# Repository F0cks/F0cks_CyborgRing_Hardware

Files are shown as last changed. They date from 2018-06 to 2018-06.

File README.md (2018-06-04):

# F0cks_CyborgRing_Hardware

I have created my own hardware and software of **Zach Fredin** [zakqwy](https://github.com/zakqwy) Cyborg ring. You can use [my Cyborg ring software](https://github.com/F0cks/F0cks_CyborgRing_Hardware) for this hardware. <br />
You can find more information on my blog : [blog.f0cks.net/projects/Cyborg-ring](https://blog.f0cks.net/projects/Cyborg-ring/).

### Description

* This hardware has been created with **Eagle Version 7.7.0**.
* All GERBER files are included in **F0cks_CyborgRing_Gerber.zip**.
* You can create directly your board using my **OSHPark Project**: <br /> 
* I have added the **BOM** with component links from Digikey (and button cells from eBay).
* You will probably need to edit the board to fit the ring to your finger ( diameter is around 17mm).

## Authors

* **Geoffrey Enjolras** - [F0cks](https://github.com/F0cks)

## License

In agreement with **Zach Fredin**, this code is released under the terms of the Creative Commons Attribution-ShareAlike 4.0 license, available here: http://creativecommons.org/licenses/by-sa/4.0/.


## Acknowledgments

Completely inspired by **Zach Fredin** [zakqwy](https://github.com/zakqwy).

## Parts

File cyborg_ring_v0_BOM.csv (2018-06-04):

Qty | Value | Device | Package | Parts | Links
1 |  | PUSHBUTTON | BTN_CK_KSS | SW1 | https://www.digikey.fr/product-detail/fr/omron-electronics-inc-emc-div/B3U-3000P/SW1022CT-ND/1534359
1 | 100n | C-EUC0201 | C0201 | C1 | https://www.digikey.fr/product-detail/fr/samsung-electro-mechanics/CL03A104KP3NNNC/1276-1115-1-ND/3889201
1 | ATTINYX5V-LEFT | ATTINYX5V-LEFT | 1/4-QFN20 | U1 | https://www.digikey.fr/product-detail/fr/microchip-technology/ATTINY85V-15MT/1611-ATTINY85V-15MTCT-ND/6833275
0 | ATTINYX5V-RIGHT | ATTINYX5V-RIGHT | 1/4-QFN20 | U2 | /
2 | BAT+ | BAT+ | BAT+ | U$1, U$2 | https://www.ebay.fr/itm/Lot-de-piles-boutons-auditives-Rayovac-appareils-auditifs-A10-de-1-%C3%A0-60-piles/272609224796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
2 | BAT- | BAT- | BAT- | U$3, U$4 | https://www.digikey.fr/product-detail/fr/te-connectivity-amp-connectors/1447360-8/A108284CT-ND/4022011
16 | R0508-1/2 | R0508-1/2 | R0508-1/2 | R13, R14, R15, R16, R17, R18, R19, R20, R21, R22, R23, R24, R25, R26, R27, R28 | https://www.digikey.fr/product-detail/fr/rohm-semiconductor/LTR10EZPF22R0/RHM1211CT-ND/4055428
12 | R0805-1/2 | R0805-1/2 | R0805-1/2 | R1, R2, R3, R4, R5, R6, R7, R8, R9, R10, R11, R12 | https://www.digikey.fr/product-detail/fr/yageo/RC0805JR-070RL/311-0.0ARCT-ND/731163
1 | TPTP06R | TPTP06R | TP06R | PAD | /
6 | TPTP15R | TPTP15R | TP15R | GND, MISO, MOSI, RST, SCK, VCC | https://www.digikey.fr/product-detail/fr/mill-max-manufacturing-corp/821-22-006-10-000101/ED8197-06-ND/1146513
8 |  | LEDS |  |  | https://www.digikey.fr/product-detail/fr/kingbright/APT1608LSECK-J3-PRV/754-1930-1-ND/5177460

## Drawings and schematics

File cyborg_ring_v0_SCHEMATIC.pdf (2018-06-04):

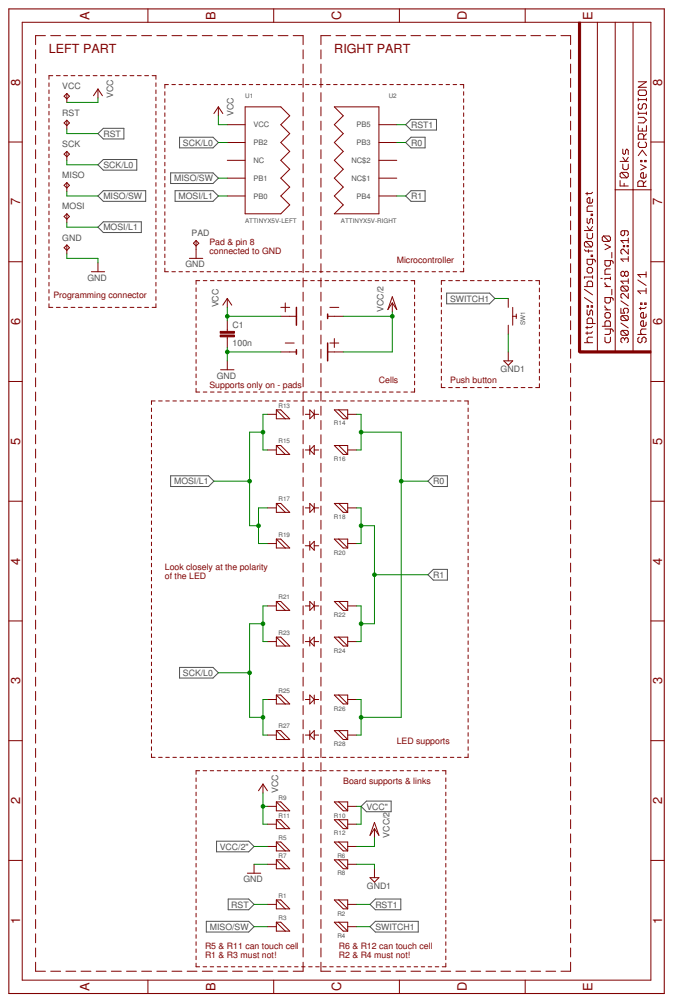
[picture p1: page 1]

GND
Supports only on - pads

Look closely at the polarity of the LED

LED supports Board supports & links

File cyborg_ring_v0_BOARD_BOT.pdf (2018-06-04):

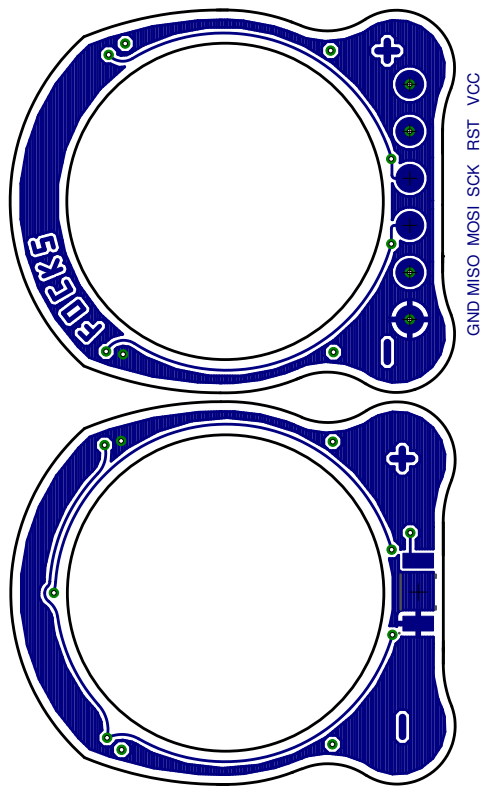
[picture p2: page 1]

GND MISO MOSI SCK RST VCC

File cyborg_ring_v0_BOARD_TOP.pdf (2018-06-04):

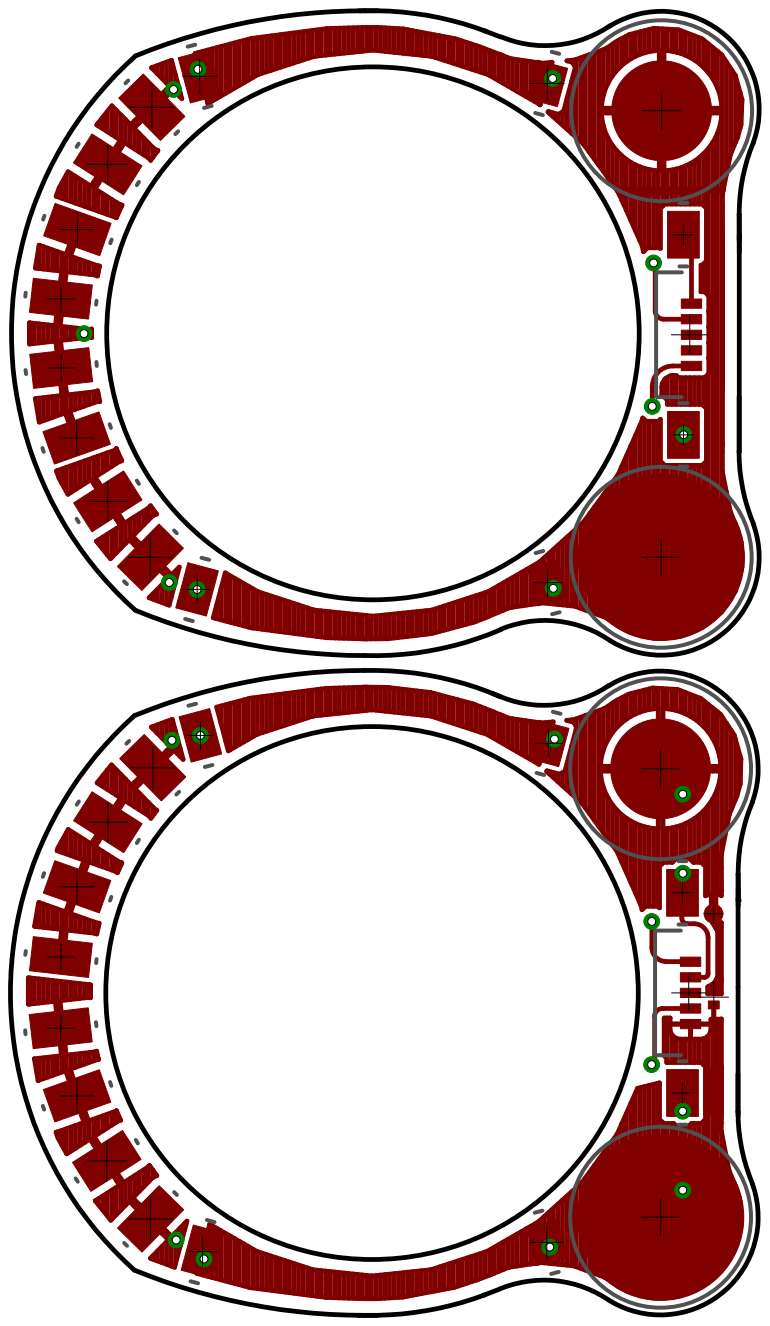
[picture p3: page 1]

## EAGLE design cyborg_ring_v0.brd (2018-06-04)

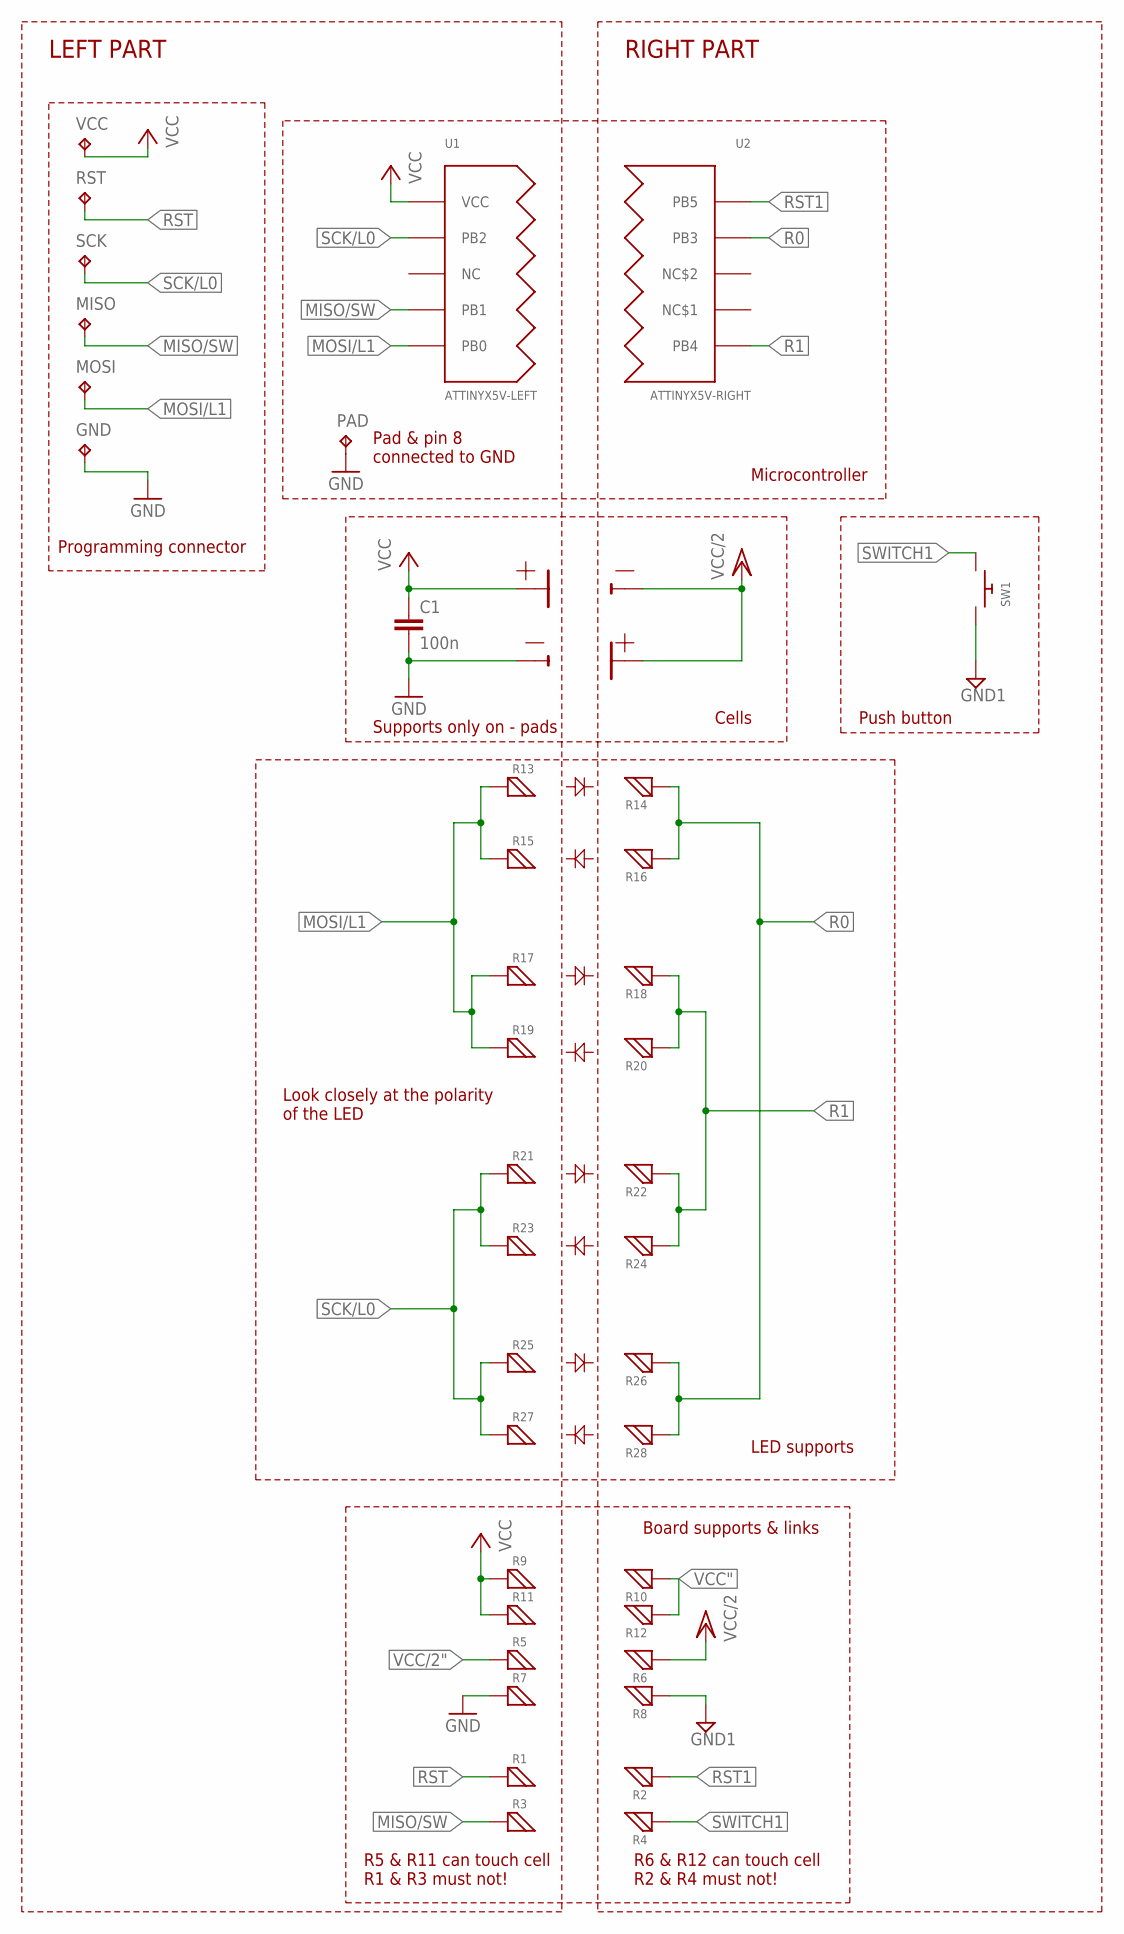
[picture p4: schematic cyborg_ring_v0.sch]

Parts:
C1: 100n; C0201
GND: TPTP15R; TP15R
MISO: TPTP15R; TP15R
MOSI: TPTP15R; TP15R
PAD: TPTP06R; TP06R
R1, R2, R3, R4, R7, R8, R9, R10: R0805-1/2TEST; R0805-1/2
R5, R6, R11, R12: R0805-1/2TEST2; R0905-1/2BIS
R13, R14, R15, R16, R17, R18, R19, R20, R21, R22, R23, R24, R25, R26, R27, R28: R0508-1/2
RST: TPTP15R; TP15R
SCK: TPTP15R; TP15R
SW1: SWITCH_PUSHBUTTONC&K_KSS; BTN_CK_KSS
U1: ATTINYX5V-LEFT; 1/4-QFN20
U2: ATTINYX5V-RIGHT; 1/4-QFN20
U$1, U$2: BAT+
U$3, U$4: BAT-
VCC: TPTP15R; TP15R

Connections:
GND: C1.2, GND.TP, PAD.TP, R7.1, U$4.P$1
GND1: R8.1, SW1.P$1
MISO/SW: MISO.TP, R3.1, U1.4 (PB1)
MOSI/L1: MOSI.TP, R13.P$1, R15.P$1, R17.P$1, R19.P$1, U1.5 (PB0)
R0: R14.P$1, R16.P$1, R26.P$1, R28.P$1, U2.4 (PB3)
R1: R18.P$1, R20.P$1, R22.P$1, R24.P$1, U2.1 (PB4)
RST: R1.1, RST.TP
RST1: R2.1, U2.5 (PB5)
SCK/L0: R21.P$1, R23.P$1, R25.P$1, R27.P$1, SCK.TP, U1.2 (PB2)
SWITCH1: R4.1, SW1.P$2
VCC: C1.1, R9.1, R11.1, U1.1 (VCC), U$1.P$1, VCC.TP
VCC": R10.1, R12.1
VCC/2: R6.1, U$2.P$1, U$3.P$1
VCC/2": R5.1

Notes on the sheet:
Pad & pin 8 connected to GND
LEFT PART
RIGHT PART
Programming connector
Microcontroller
Cells
LED supports
Board supports & links
Push button
R5 & R11 can touch cell R1 & R3 must not!
R6 & R12 can touch cell R2 & R4 must not!
Look closely at the polarity of the LED
Supports only on - pads

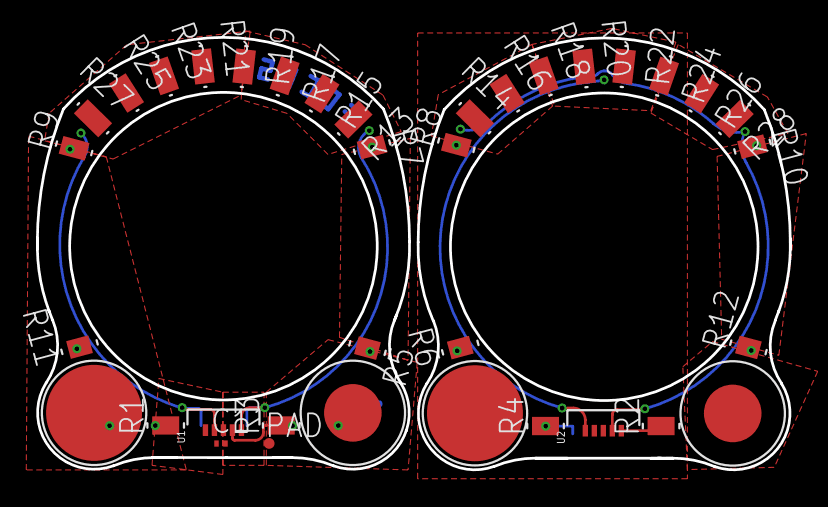
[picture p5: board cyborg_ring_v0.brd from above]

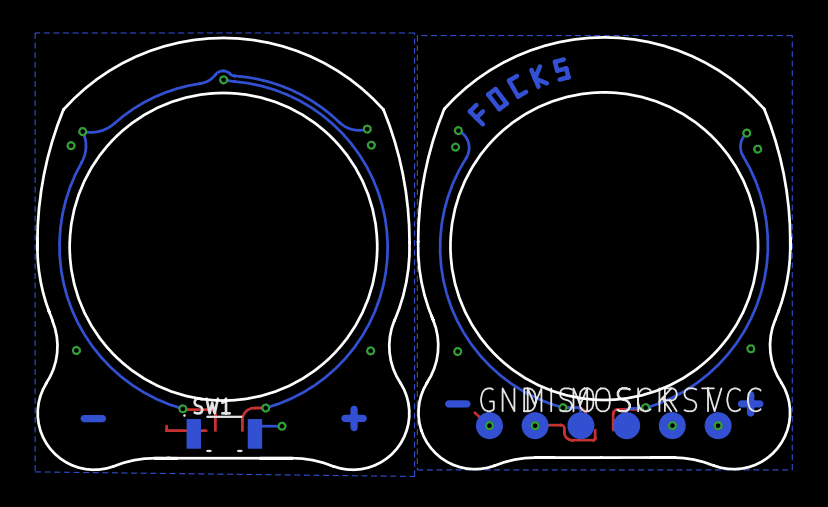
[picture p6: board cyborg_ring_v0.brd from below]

Board: 2 copper layers, 41.8 x 24.0 mm, 43 parts (7 on the bottom side), 13 nets.

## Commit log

2018-05-29 Clean files
    [cyborg_ring_v0.brd, cyborg_ring_v0.sch]
2018-05-29 Adding GERBER files
2018-05-30 Clearer schematic
    [cyborg_ring_v0.brd, cyborg_ring_v0.sch]
2018-05-30 BOM added
    [cyborg_ring_v0_BOM.csv]
2018-05-30 Schematic and board in .pdf added

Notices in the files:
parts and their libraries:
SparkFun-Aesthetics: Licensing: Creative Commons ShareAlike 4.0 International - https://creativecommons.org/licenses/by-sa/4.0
